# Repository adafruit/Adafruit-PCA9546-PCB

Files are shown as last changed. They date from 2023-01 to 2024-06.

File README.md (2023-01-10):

## Adafruit PCA9546 4-Channel I2C Multiplexer PCB

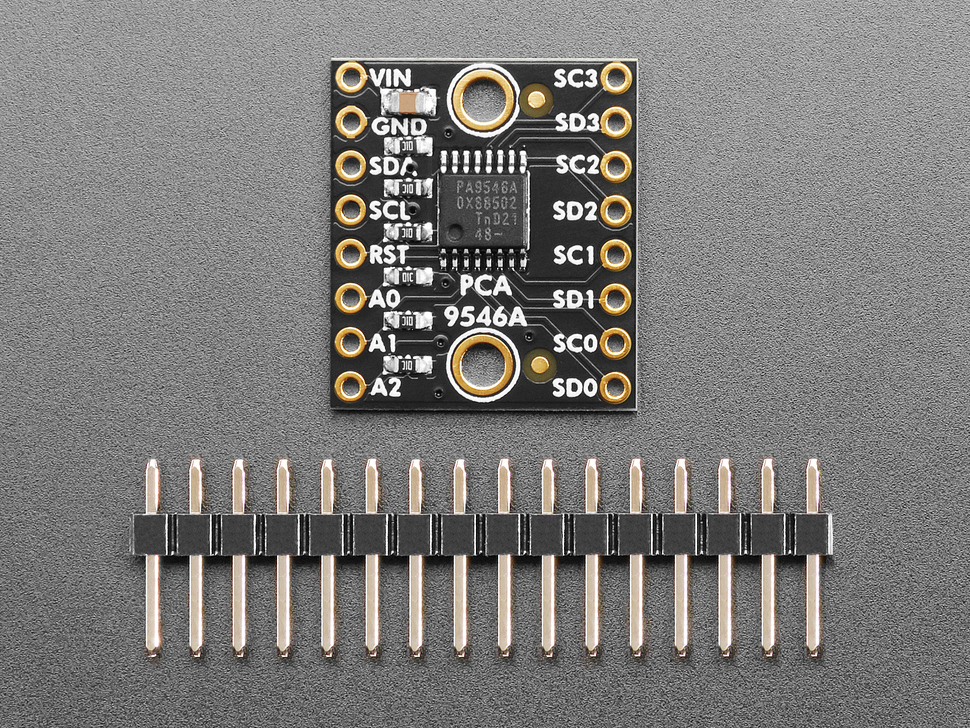
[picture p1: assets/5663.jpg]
<a href="http://www.adafruit.com/products/5663"><br/>
Click here to purchase one from the Adafruit shop</a>
<br>
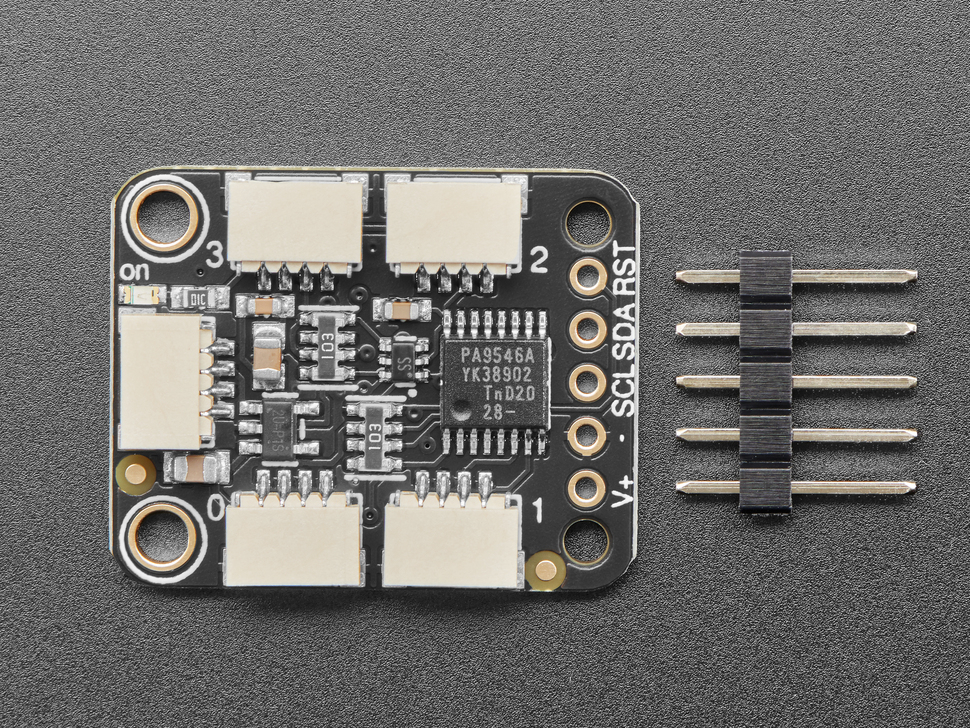
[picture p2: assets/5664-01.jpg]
<a href="http://www.adafruit.com/products/5664"><br/>
Click here to purchase one from the Adafruit shop</a>

PCB files for the Adafruit PCA9546 4-Channel I2C Multiplexer and STEMMA QT / Qwiic PCA9546 Breakout. 

Format is EagleCAD schematic and board layout
* https://www.adafruit.com/product/5663
* https://www.adafruit.com/product/5664

### Description

You just found the perfect I2C sensor, and you want to wire up two or three or more of them to your Arduino when you realize "Uh oh, this chip has a fixed I2C address, and from what I know about I2C, you cannot have two devices with the same address on the same SDA/SCL pins!" Are you out of luck? You would be if you didn't have this ultra-cool PCA9546 1-to-4 I2C multiplexer!

Finally, a way to get up to 4 same-address I2C devices hooked up to one microcontroller - this multiplexer acts as a gatekeeper, shuttling the commands to the selected set of I2C pins with your command.  If you need to have up to 8 multiplexed devices, check out the 8-channel TCA9548 version of this board.

Using it is fairly straight-forward: the multiplexer itself is on I2C address 0x70 (but can be adjusted from 0x70 to 0x77) and you simply write a single byte with the desired multiplexed output number to that port, and bam - any future I2C packets will get sent to that port. In theory, you could have 8 of these multiplexers on each of 0x70-0x77 addresses in order to control 8*4 = 32 of the same-I2C-addressed-part.

Like all Adafruit breakouts, we put this nice chip on a breakout for you so you can use it on a breadboard with capacitors, and pullups and pulldowns to make usage a snap. Some header is required, and once soldered, you can plug it into a solderless breadboard. The chip itself is 3V and 5V compliant, so you can use it with any logic level.

Comes with only the assembled PCB, no cables or sensors included (we have tons available though!)

The Adafruit STEMMA QT / Qwiic PCA9546 Breakout - 4 Channel has five JST SH 1mm connectors: 1 input and 4 outputs. There's one port at the end that connects to your I2C controller (there are also breadboard breakout pins if you need them). Use this breakout to add as many I2C devices to the bus as you need. Complete with mounting holes so the board can be added to any system. A small power LED lets you know that the hub board has connectivity.

There's even an onboard 3.3V 500mA regulator, so if you're using this with a 5V microcontroller like an Arduino 328-compatible, you can level shift all the QT ports to have 3V power and logic level. Simply cut/solder the jumper on the bottom of the PCB to change the power and logic level to be forced 3V.

### License

Adafruit invests time and resources providing this open source design, please support Adafruit and open-source hardware by purchasing products from [Adafruit](https://www.adafruit.com)!

Designed by Limor Fried/Ladyada for Adafruit Industries.

Creative Commons Attribution/Share-Alike, all text above must be included in any redistribution. 
See license.txt for additional details.

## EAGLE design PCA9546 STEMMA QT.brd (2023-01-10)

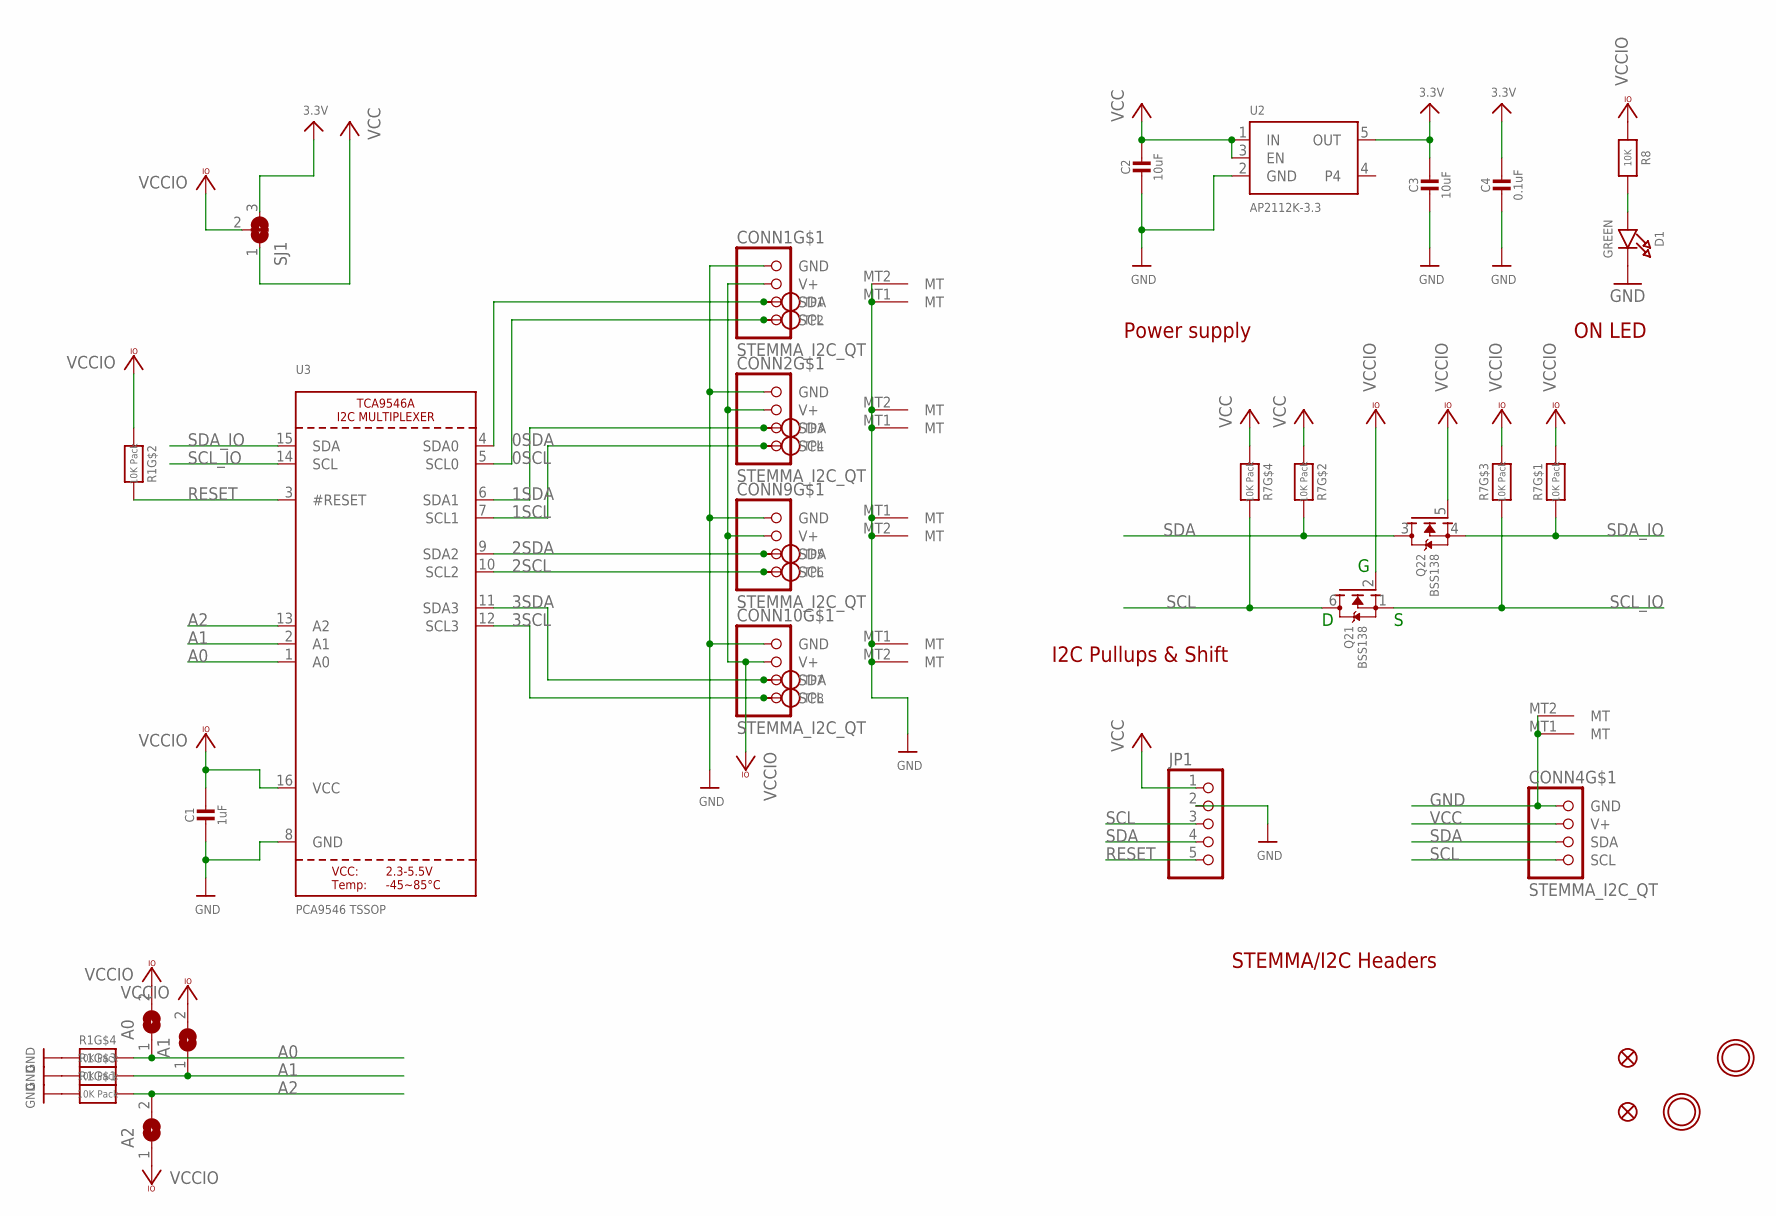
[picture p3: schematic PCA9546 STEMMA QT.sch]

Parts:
A0, A1, A2: SOLDERJUMPER; SOLDERJUMPER_ARROW_NOPASTE
C1: 1uF; 0603-NO
C2, C3: 10uF; 0805-NO
C4: 0.1uF; 0603-NO
CONN1, CONN2, CONN4, CONN9, CONN10: STEMMA_I2C_QT; JST_SH4
D1: GREEN; CHIPLED_0603_NOOUTLINE
FID2, FID4: FIDUCIAL_1MM
JP1: HEADER-1X570MIL; 1X05_ROUND_70
Q2: BSS138; SOT363
R1, R7: 10K Pack; RESPACK_4X0603
R8: 10K; 0603-NO
SJ1: SOLDERJUMPER_2WAY; SOLDERJUMPER_2WAY_OPEN_NOPASTE
TP1, TP2, TP3, TP4, TP5, TP6, TP7, TP8: TESTPOINTROUND1.5MMNO; TESTPOINT_ROUND_1.5MM_NO
U2: AP2112K-3.3; SOT23-5; JLC_ROTATION 0
U3: PCA9546 TSSOP; TSSOP16
U$19, U$22: MOUNTINGHOLE2.5; MOUNTINGHOLE_2.5_PLATED

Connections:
0SCL: CONN1.4 (SCL), TP2.P$1, U3.5 (SCL0)
0SDA: CONN1.3 (SDA), TP1.P$1, U3.4 (SDA0)
1SCL: CONN2.4 (SCL), TP4.P$1, U3.7 (SCL1)
1SDA: CONN2.3 (SDA), TP3.P$1, U3.6 (SDA1)
2SCL: CONN9.4 (SCL), TP6.P$1, U3.10 (SCL2)
2SDA: CONN9.3 (SDA), TP5.P$1, U3.9 (SDA2)
3.3V: C3.1, C4.1, SJ1.3, U2.5 (OUT)
3SCL: CONN10.4 (SCL), TP8.P$1, U3.12 (SCL3)
3SDA: CONN10.3 (SDA), TP7.P$1, U3.11 (SDA3)
A0: A0.1, R1.5 (2), U3.1 (A0)
A1: A1.1, R1.6 (2), U3.2 (A1)
A2: A2.2, R1.8 (2), U3.13 (A2)
GND: C1.2, C2.2, C3.2, C4.2, CONN1.1 (GND), CONN1.MT1 (MT), CONN1.MT2 (MT), CONN2.1 (GND), CONN2.MT1 (MT), CONN2.MT2 (MT), CONN4.1 (GND), CONN4.MT1 (MT), CONN4.MT2 (MT), CONN9.1 (GND), CONN9.MT1 (MT), CONN9.MT2 (MT), CONN10.1 (GND), CONN10.MT1 (MT), CONN10.MT2 (MT), D1.C, JP1.2, R1.1, R1.3 (1), R1.4 (1), U2.2 (GND), U3.8 (GND)
unnamed: D1.A, R8.2
RESET: JP1.5, R1.7 (2), U3.3 (#RESET)
SCL: CONN4.4 (SCL), JP1.3, Q2.6 (D), R7.5 (2)
SCL_IO: Q2.1 (S), R7.6 (2), U3.14 (SCL)
SDA: CONN4.3 (SDA), JP1.4, Q2.3 (D), R7.7 (2)
SDA_IO: Q2.4 (S), R7.8 (2), U3.15 (SDA)
VCC: C2.1, CONN4.2 (V+), JP1.1, R7.2 (1), R7.4 (1), SJ1.1, U2.1 (IN), U2.3 (EN)
VCCIO: A0.2, A1.2, A2.1, C1.1, CONN1.2 (V+), CONN2.2 (V+), CONN9.2 (V+), CONN10.2 (V+), Q2.2 (G), Q2.5 (G), R1.2 (1), R7.1, R7.3 (1), R8.1, SJ1.2, U3.16 (VCC)

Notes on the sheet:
I2C Pullups & Shift
STEMMA/I2C Headers
ON LED
Power supply

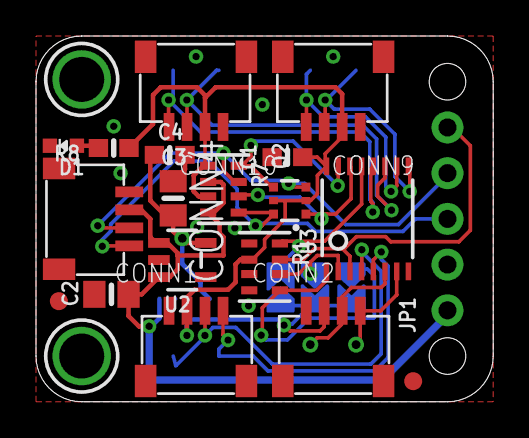
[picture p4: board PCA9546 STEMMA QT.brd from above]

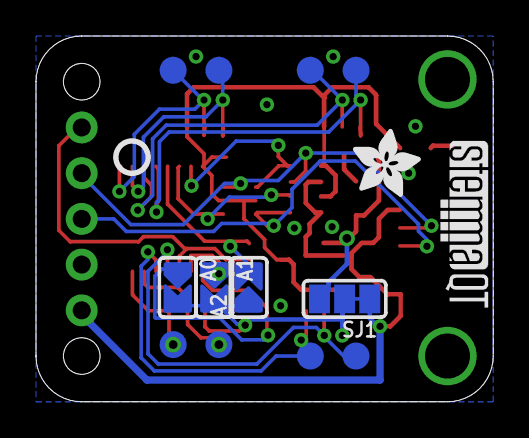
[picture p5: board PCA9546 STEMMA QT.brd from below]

Board: 2 copper layers, 25.4 x 20.3 mm, 55 parts (24 on the bottom side), 21 nets.

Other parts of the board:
PLABEL0: PLABEL0
PLABEL1: PLABEL1
PLABEL2: PLABEL2
PLABEL3: PLABEL3
PLABEL4: PLABEL4
PLABEL5: PLABEL5
PLABEL6: PLABEL6
PLABEL7: PLABEL7
PLABEL8: PLABEL8
PLABEL9: PLABEL9
PLABEL10: PLABEL10
PLABEL11: PLABEL11
PLABEL12: PLABEL12
PLABEL13: PLABEL13
PLABEL14: PLABEL14
PLABEL15: PLABEL15
PLABEL16: PLABEL16
PLABEL17: PLABEL17
PLABEL18: PLABEL18
U$28: ADAFRUIT_3.5MM
U$29: PCBFEAT-REV-040
U$31: STEMMAQT

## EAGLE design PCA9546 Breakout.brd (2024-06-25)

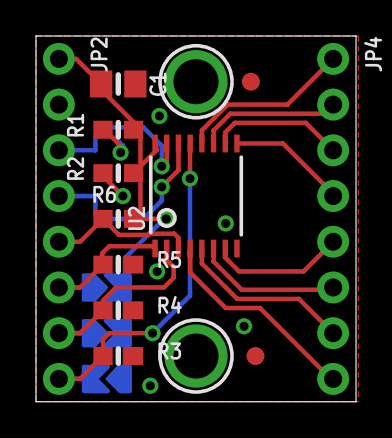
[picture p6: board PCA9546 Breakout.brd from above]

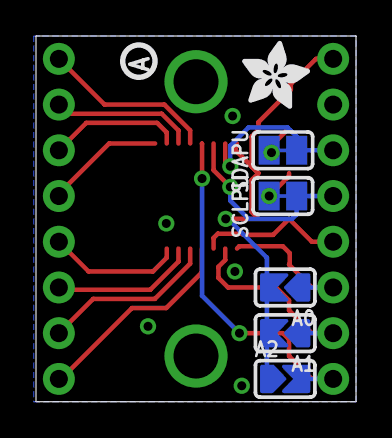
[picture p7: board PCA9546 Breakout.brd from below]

Board: 2 copper layers, 17.8 x 20.3 mm, 44 parts (13 on the bottom side), 18 nets.

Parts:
A0, A1, A2: SOLDERJUMPER_ARROW_NOPASTE
C1: 10uF; 0805-NO
FID1, FID3: FIDUCIAL_1MM
JP2, JP4: 1X08_ROUND_70
PLABEL0: PLABEL0
PLABEL1: PLABEL1
PLABEL2: PLABEL2
PLABEL3: PLABEL3
PLABEL4: PLABEL4
PLABEL5: PLABEL5
PLABEL6: PLABEL6
PLABEL7: PLABEL7
PLABEL8: PLABEL8
PLABEL9: PLABEL9
PLABEL10: PLABEL10
PLABEL11: PLABEL11
PLABEL12: PLABEL12
PLABEL13: PLABEL13
PLABEL14: PLABEL14
PLABEL15: PLABEL15
PLABEL16: PLABEL16
PLABEL17: PLABEL17
PLABEL18: PLABEL18
PLABEL19: PLABEL19
PLABEL20: PLABEL20
PLABEL21: PLABEL21
PLABEL22: PLABEL22
R1, R2, R3, R4, R5, R6: 10K; 0603-NO
SCLPU: SOLDERJUMPER_CLOSEDWIRE
SDAPU: SOLDERJUMPER_CLOSEDWIRE
U2: PCA9546A TSSOP; TSSOP16
U$4, U$5: MOUNTINGHOLE2.5; MOUNTINGHOLE_2.5_PLATED
U$6: PCBFEAT-REV-040
U$7: ADAFRUIT_3.5MM

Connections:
0SCL: JP4.7, U2.5
0SDA: JP4.8, U2.4
1SCL: JP4.5, U2.7
1SDA: JP4.6, U2.6
2SCL: JP4.3, U2.10
2SDA: JP4.4, U2.9
3SCL: JP4.1, U2.12
3SDA: JP4.2, U2.11
A0: A0.1, JP2.6, R5.1, U2.1
A1: A1.1, JP2.7, R4.1, U2.2
A2: A2.2, JP2.8, R3.1, U2.13
GND: C1.2, JP2.2, R3.2, R4.2, R5.2, U2.8
INPUTSCL: JP2.4, SCLPU.1, U2.14
INPUTSDA: JP2.3, SDAPU.1, U2.15
unnamed: R2.1, SCLPU.2
unnamed: R1.1, SDAPU.2
RESET: JP2.5, R6.1, U2.3
VCC: A0.2, A1.2, A2.1, C1.1, JP2.1, R1.2, R2.2, R6.2, U2.16

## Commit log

2023-01-10 adding cookiecutter output
    [PCA9546 Breakout.brd, PCA9546 Breakout.sch, PCA9546 STEMMA QT.brd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]
2024-06-25 new silk
    [PCA9546 Breakout.brd]

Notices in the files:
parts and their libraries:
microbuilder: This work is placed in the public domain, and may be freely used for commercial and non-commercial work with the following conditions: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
